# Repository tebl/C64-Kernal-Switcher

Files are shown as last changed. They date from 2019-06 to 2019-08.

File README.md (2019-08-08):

# C64 Kernal Switcher

Originally started this design with the idea of using an Arduino as a way to switch between Commodore 64 kernal ROMs, but ended up adapting BWACKs design into it instead and like him opted for the PIC12F629 instead. This particular version of a quad kernal switcher for the Commodore 64 is only compatible with Commodore 64 "longboards" (usually breadbins, but you never really know what you get with Commodore so check first).

BWACKs design has been adapted into mine, changing along the way a few of the features to my liking - in particular, reusing the original power LEDs as well as support for manual switches (find it more adaptable that way). Original pinouts and RGB headers have been kept the same in order to not have to do a manual like he did, but note that I've rotated them for easier use with angled pin headers to save on space within the newer and tighter C64C-style cases. Reusing the original LED makes it easier because RGB LEDs in a size that fits a C64C case is harder to find, not to mention fiddly to wire up for beginners with access to a soldering iron.

With only the single LED available, the code supplied with this project has been rewritten so that when you hold down the RESTORE it counts the flashes - then when you let go it performs the actions according to the following list:

1. RESET
2. Next kernal
3. Kernal 0
4. Kernal 1
5. Kernal 2
6. Kernal 3

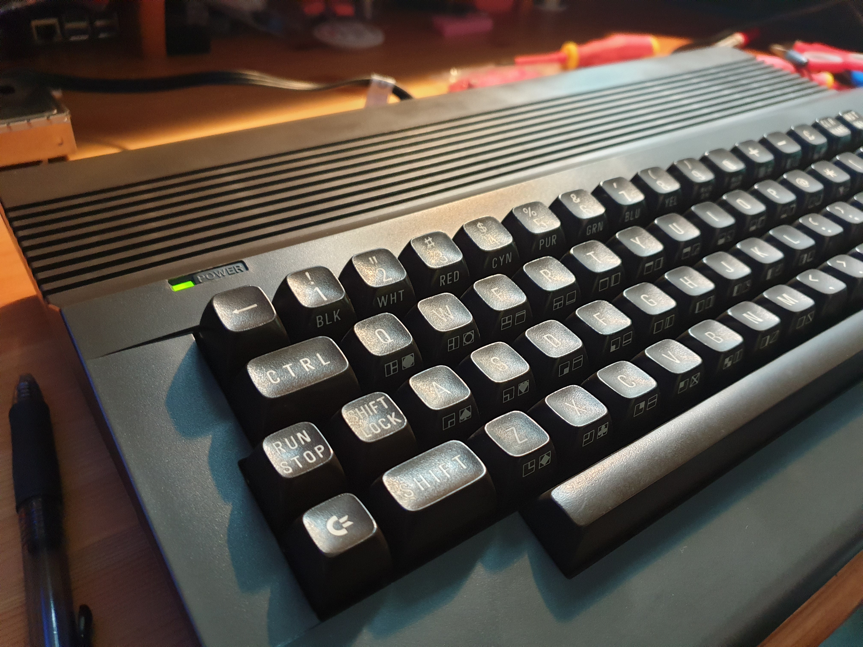
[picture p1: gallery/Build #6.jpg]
Single LED


The board itself should be functionally identical to the one made by [bwack](https://github.com/bwack/C64-Switchless-Multi-Kernal-27C256-adapter), if you want the original behavior using the RGB header with an RGB LED - use the code provided with that project.

## Building the switcher
Soldering together the few components should be easy going as long as you have access to reasonable tools, personally I'm using a cheap soldering station with adjustable temperature so no need to go expensive if you don't have to. Use 60/40 soldering tin, the lead free makes to job a lot harder if you're new to the hobby.

Start by studying the PCB, both sides and perform dry fits to see that you have an idea of where everything goes since removing things is always a lot harder than getting it right in the first place (match orientation to symbols, see gallery images for reference).

With a lot going on for such a tiny board, you'd need to pay some attention to the sequence of components getting soldered in. The list below is the one I recommend, note that with some sockets you'll have less space underneath and it'll be a lot easier getting it into place if you trim the pins after they have been soldered into place. When aligning the two 12-pin (round) pin-headers I recommend using a round-pin socket to help keep them straight, that way you won't get issues trying to install it into the Commodore 64.

1. Resistors
2. 8-pin socket (solder on reverse-side)
3. 12pin-header on the right side (solder on reverse-side)
4. 28-pin socket
5. 12-pin header on the left side (solder on reverse-side)
6. Capacitor
7. Remaining pin headers as needed

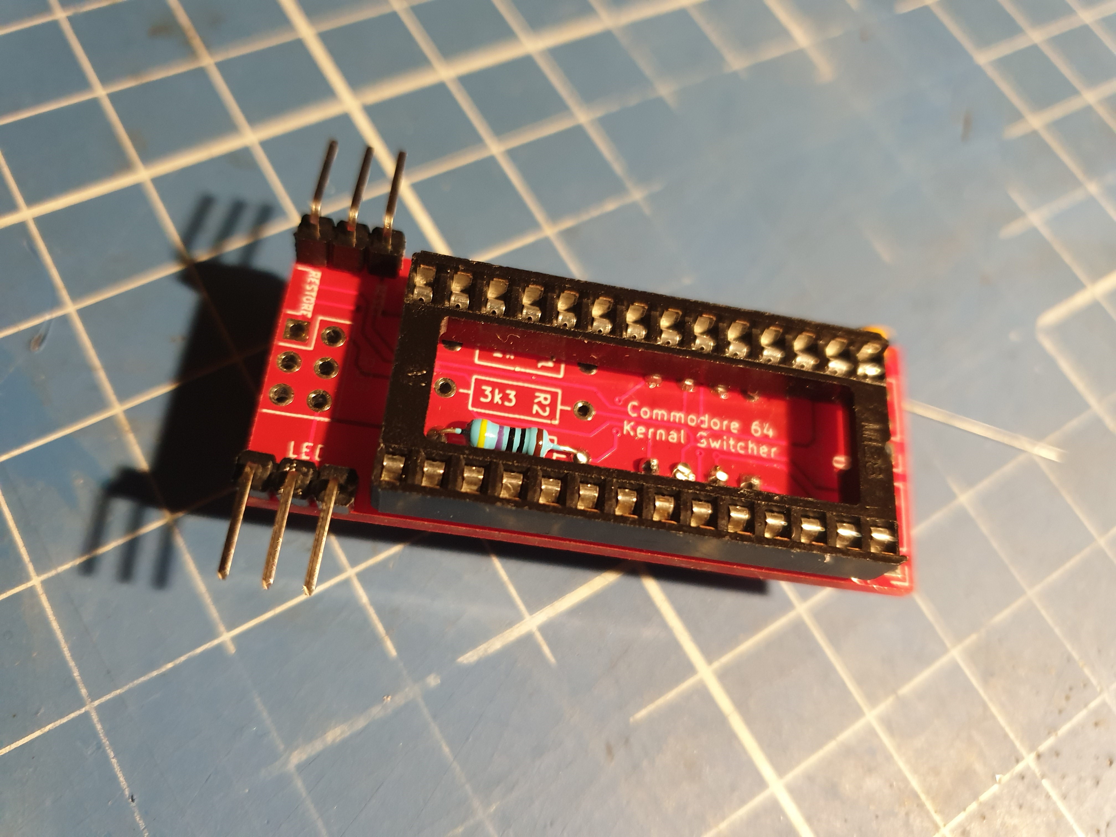
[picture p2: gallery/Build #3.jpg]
Topside

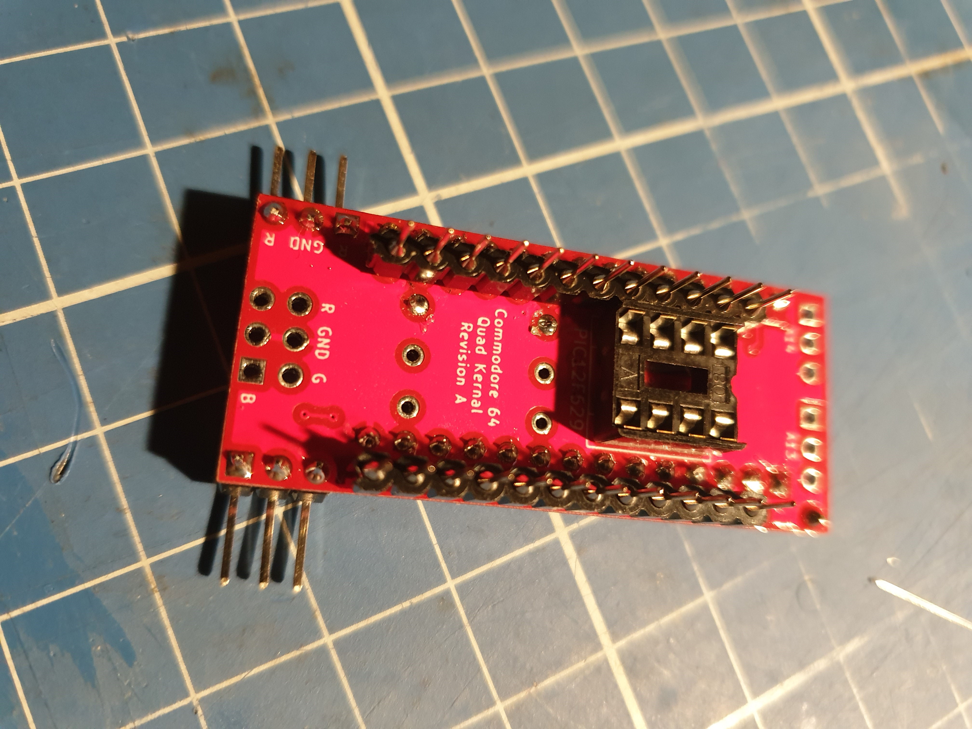
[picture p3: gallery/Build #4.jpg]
Underside


### Alternative build
The PCB doubles up as a 27c256 to 2364 adapter board, which means that you can also use it to replace the other ROM ICs used in the longboard versions of the motherboard. While there aren't many alternatives available for the basic and character ROM, but replacing them may lead to lower power use as well as decreased heat within the computer case - personally I use one as a handy way of having a 4-in-1 replacement when troubleshooting failed systems. The build process is the same as the one above, but there is no need to add resistors, 12-pin socket since the 12f629 won't be used and then add pin headers at the top in order select active ROM image. You can generate a suitable bin-file to flash 27c256 using the following command (substitute kernal4 with one of your own choice):

`copy /b basic.901226-01.bin+kernal.901227-03.bin+characters.901225-01.bin+kernal4.bin 27C256_longboard_4in1.bin`

## Installation
First of all, check that you have a C64 with a "longboard", these are physically larger - the later common C64C boards had combined basic and kernal ROMs on a single chip, requiring a different solution altogether! First locate the kernal ROM, it should be marked 901227-03 and preferably already socketed.

If it is not socketed and you don't have experience desoldering ICs from older PCBs, I would suggest that you have someone with more experience perform this task for you - if you still go through with it, you live with the consequences! If you are really doing it anyway, cut off all the legs as close to the IC as possible and then remove leftovers with tweezers and solder-braid - IC will be dead, but the board itself will probably be happier!

When installing in the computer, the pin on the bottom are inserted into the socket. You'll now need to find suitable places to attach the signal wires to the mainboard, you'll need to find a spot for the RESET and the RESTORE lines. RESET will have continuity to pin 40 on the 6510 processor, a spot for RESTORE can be found by tracing from pin 3 of the keyboard connector (pin 2 is missing). As with all things Commodore, Ray Carlsen will probably have a picture of those points for your specific revision so take a look [http://personalpages.tds.net/~rcarlsen/cbm/switchless%20JiffyDOS/](http://personalpages.tds.net/~rcarlsen/cbm/switchless%20JiffyDOS/).

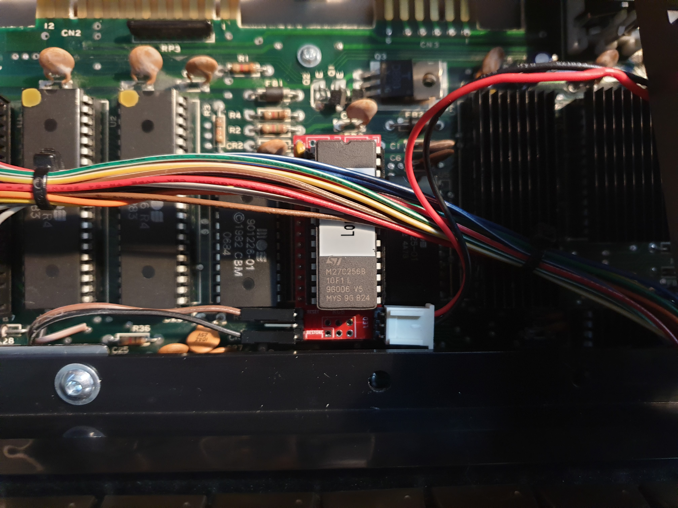
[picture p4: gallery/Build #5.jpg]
Installed


## Kernals
There have been made several kernals for the Commodore 64, this solution allows you to add 3 other kernals in addition to the original one (you'll need it for compatibility). Among my favourites are the [SD2IEC Kernal ROM](https://csdb.dk/release/?id=159050), [Turbo Tape Kernal ROM](https://csdb.dk/release/?id=47403) and [JiffyDOS](http://www.go4retro.com/products/jiffydos/). Note that JiffyDOS, while a popular choice is still under license so you should therefore seek to obtain a registered license for it!

On windows you can generate a 32kb file with your selected kernals by using the copy command, this can then be flashed to a blank 27C256 EPROM. Substitute kernals 2-4 with those of your choice:

`copy /b kernal.901227-03.bin+kernal2.bin+kernal3.bin+kernal4.bin 27C256_breadbin.bin`

Custom ROM

# Original design
As a large part of this project, schematic and code, was based on the one originally made by bwack, I've included the following section from that projects README.txt here in accordance with the license specified.

> C64 Switchless Multi Kernel Switch
> \- 27C256 rom adapter for C64's with long motherboard

> Designed by BWACK.
> CERN OPEN HARDWARE LICENSE v1.2
> http://www.ohwr.org/

> The Eagle CAD files are available on GitHub:
> https://github.com/bwack/C64-Switchless-Multi-Kernal-27C256-adapter

> All text above must be included in any redistribution

# Schematic
The supplied KiCad files should be sufficient as both a schematic and as a  starting point for ordering PCBs (basically you could just zip the contents of the export folder and upload that on a fabrication site), the schematic is also available in [PDF-format](https://github.com/tebl/C64_Kernal_Switcher/raw/master/export/C64%20Kernal%20Switcher.pdf) and this is what you'll need to print and work your way through this things don't work as expected after assembly.

# BOM
Most parts should be easy to get a hold of from your favourite local electronic component shop, but given that I don't have access to such shops where I live so everything was based on whatever I could get cheapest from ebay/AliExpress (free shipping, plan on usually waiting 3-4 weeks though). The list below should be everything you'll need in addition to a workable soldering iron and some 60/40 soldering tin. Other tools needed for this project is an EPROM-ereaser as well as an EPROM-programmer for the two ICs (I use MiniPro TL866 for both).

Pin headers you order in bulk and snap off parts as needed, but note that you should get round pin headers for the part that goes into the socket - while you can use the regular kind, you may easily wear out or break the socket.

Components in parenthesis are those used for extra features, you can omit these if you want to or have no need of those features (adding switches makes no sense if using MCU). RGB header can be left off, this is optional if you wish to use code from the original project! Sockets are always recommended though technically not needed.

| Reference | Item | Count |
| --- | --- | ----- |
| PCB | Fabricate using Gerber files ([order](https://www.pcbway.com/project/shareproject/Commodore_64_Quad_Kernal_Switcher.html?inviteid=88707)) | 1 |
| C1 | 100nF capacitor | 1 |
| R1 | 1k ohm resistor | (1) | 
| R2 | 3k3 ohm resistor | (1) |
| R3 | 560 ohm resistor | 1 |
| U1 | 12-pin straight round header | 2 |
| U2 | PIC12F629 DIP-8 | 1 |
| U2 (socket)  | 8-pin socket | (1) |
| U3 | 27C256 EPROM DIP-28 | 1 |
| U3 (socket)  | 28-pin wide socket | (1) |
| A13,A14 | 3-pin straight header | (2) |
| Signal, LED  | 3-pin angled header | 2 |
| RGB | 2x3-pin straight header | (1) |

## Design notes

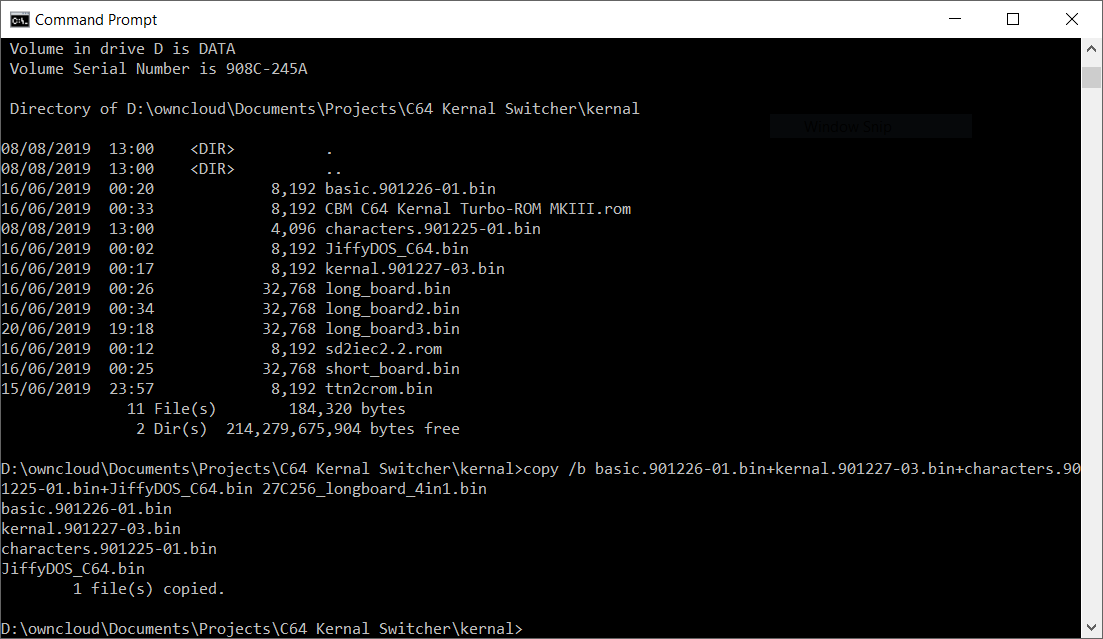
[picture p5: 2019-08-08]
gallery/27c256 #1b.PNG

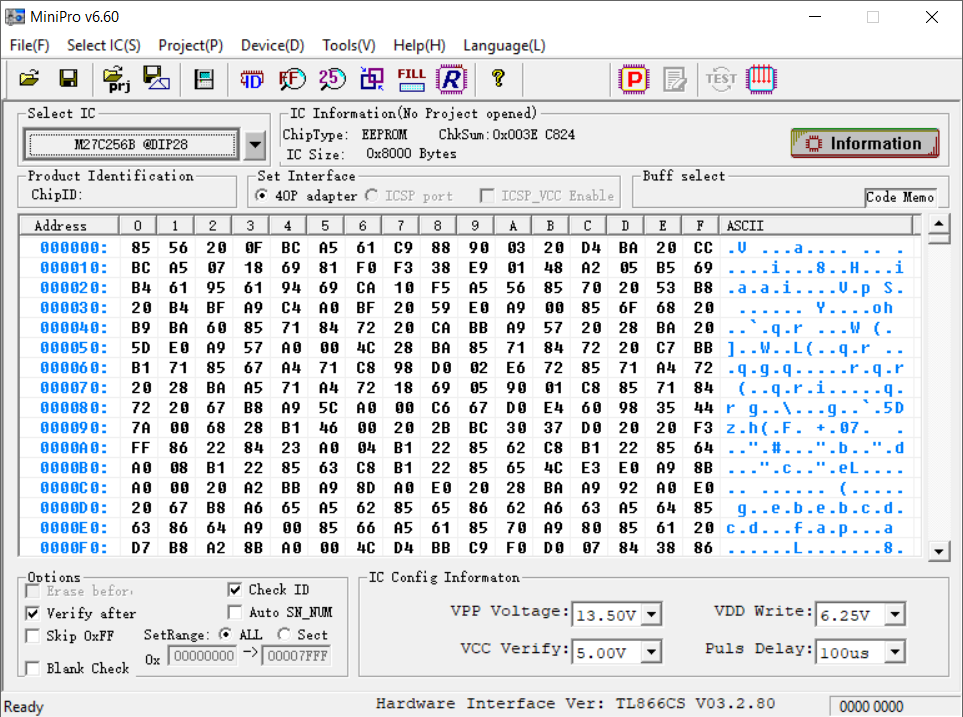
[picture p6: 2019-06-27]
gallery/27c256 #4.PNG

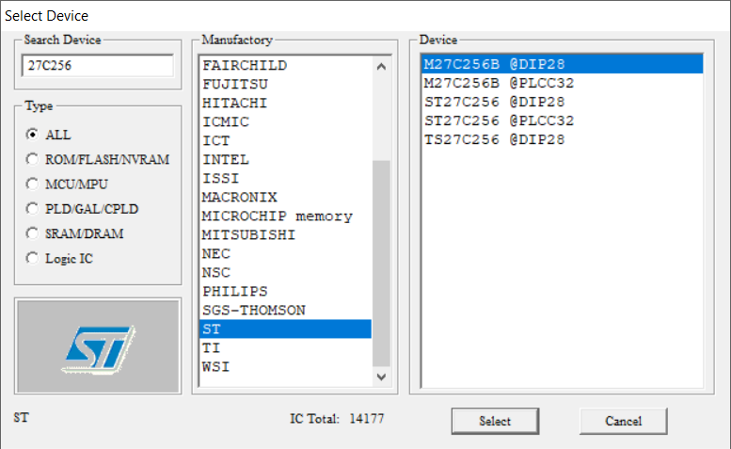
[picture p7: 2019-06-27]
gallery/27c256 #2.PNG

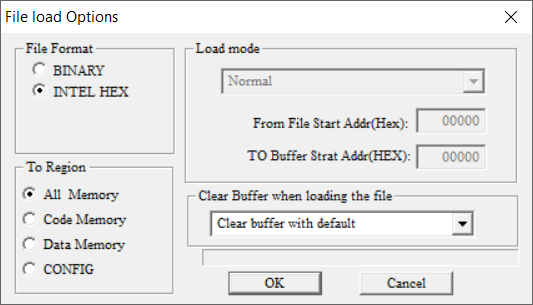
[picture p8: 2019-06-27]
gallery/12f629 #2.PNG

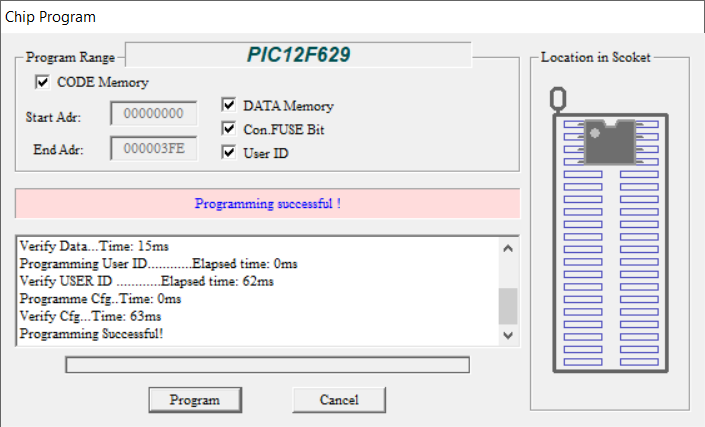
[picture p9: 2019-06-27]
gallery/12f629 #4.PNG

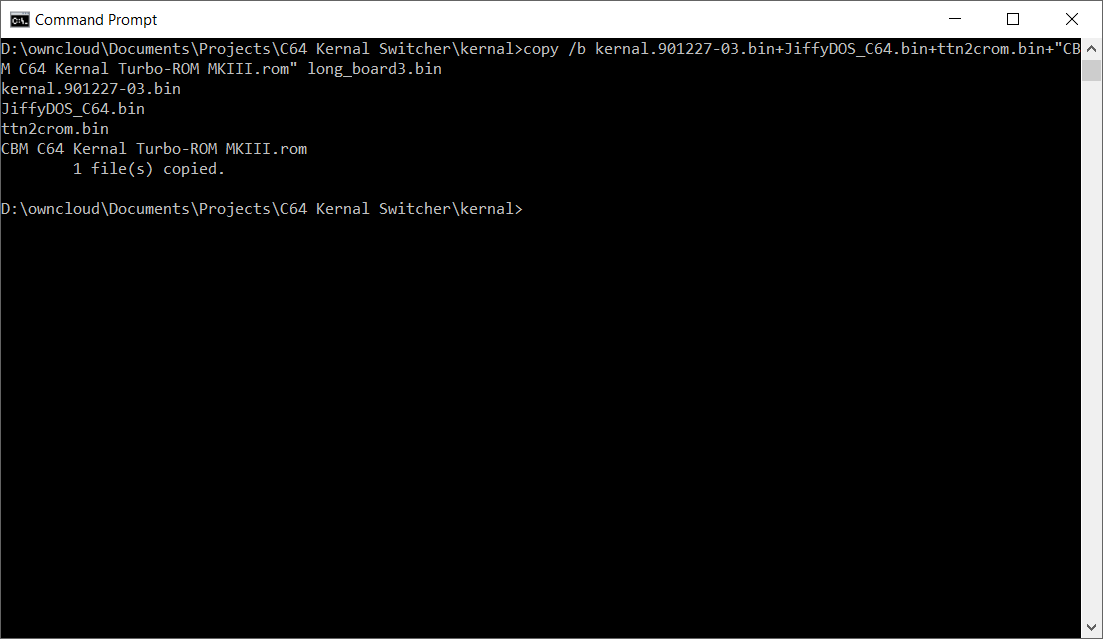
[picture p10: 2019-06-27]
gallery/27c256 #1.PNG

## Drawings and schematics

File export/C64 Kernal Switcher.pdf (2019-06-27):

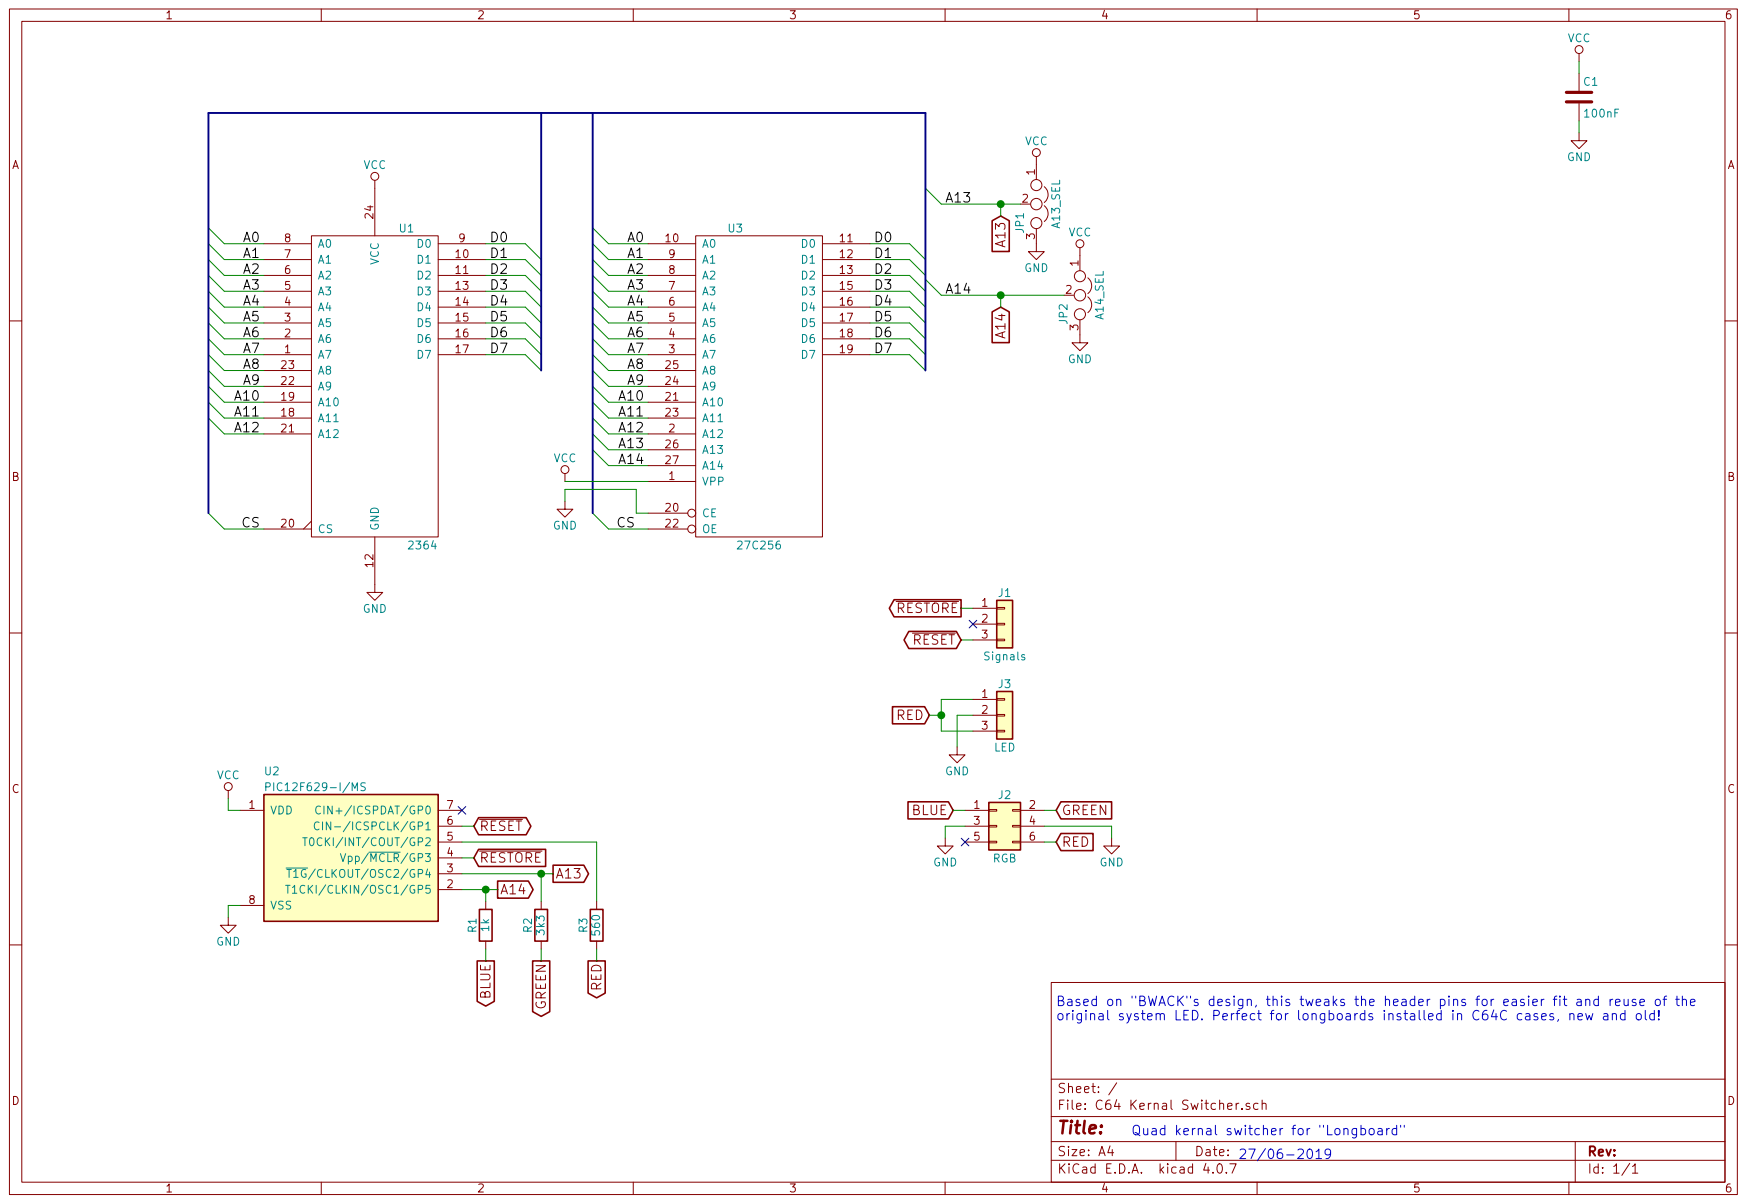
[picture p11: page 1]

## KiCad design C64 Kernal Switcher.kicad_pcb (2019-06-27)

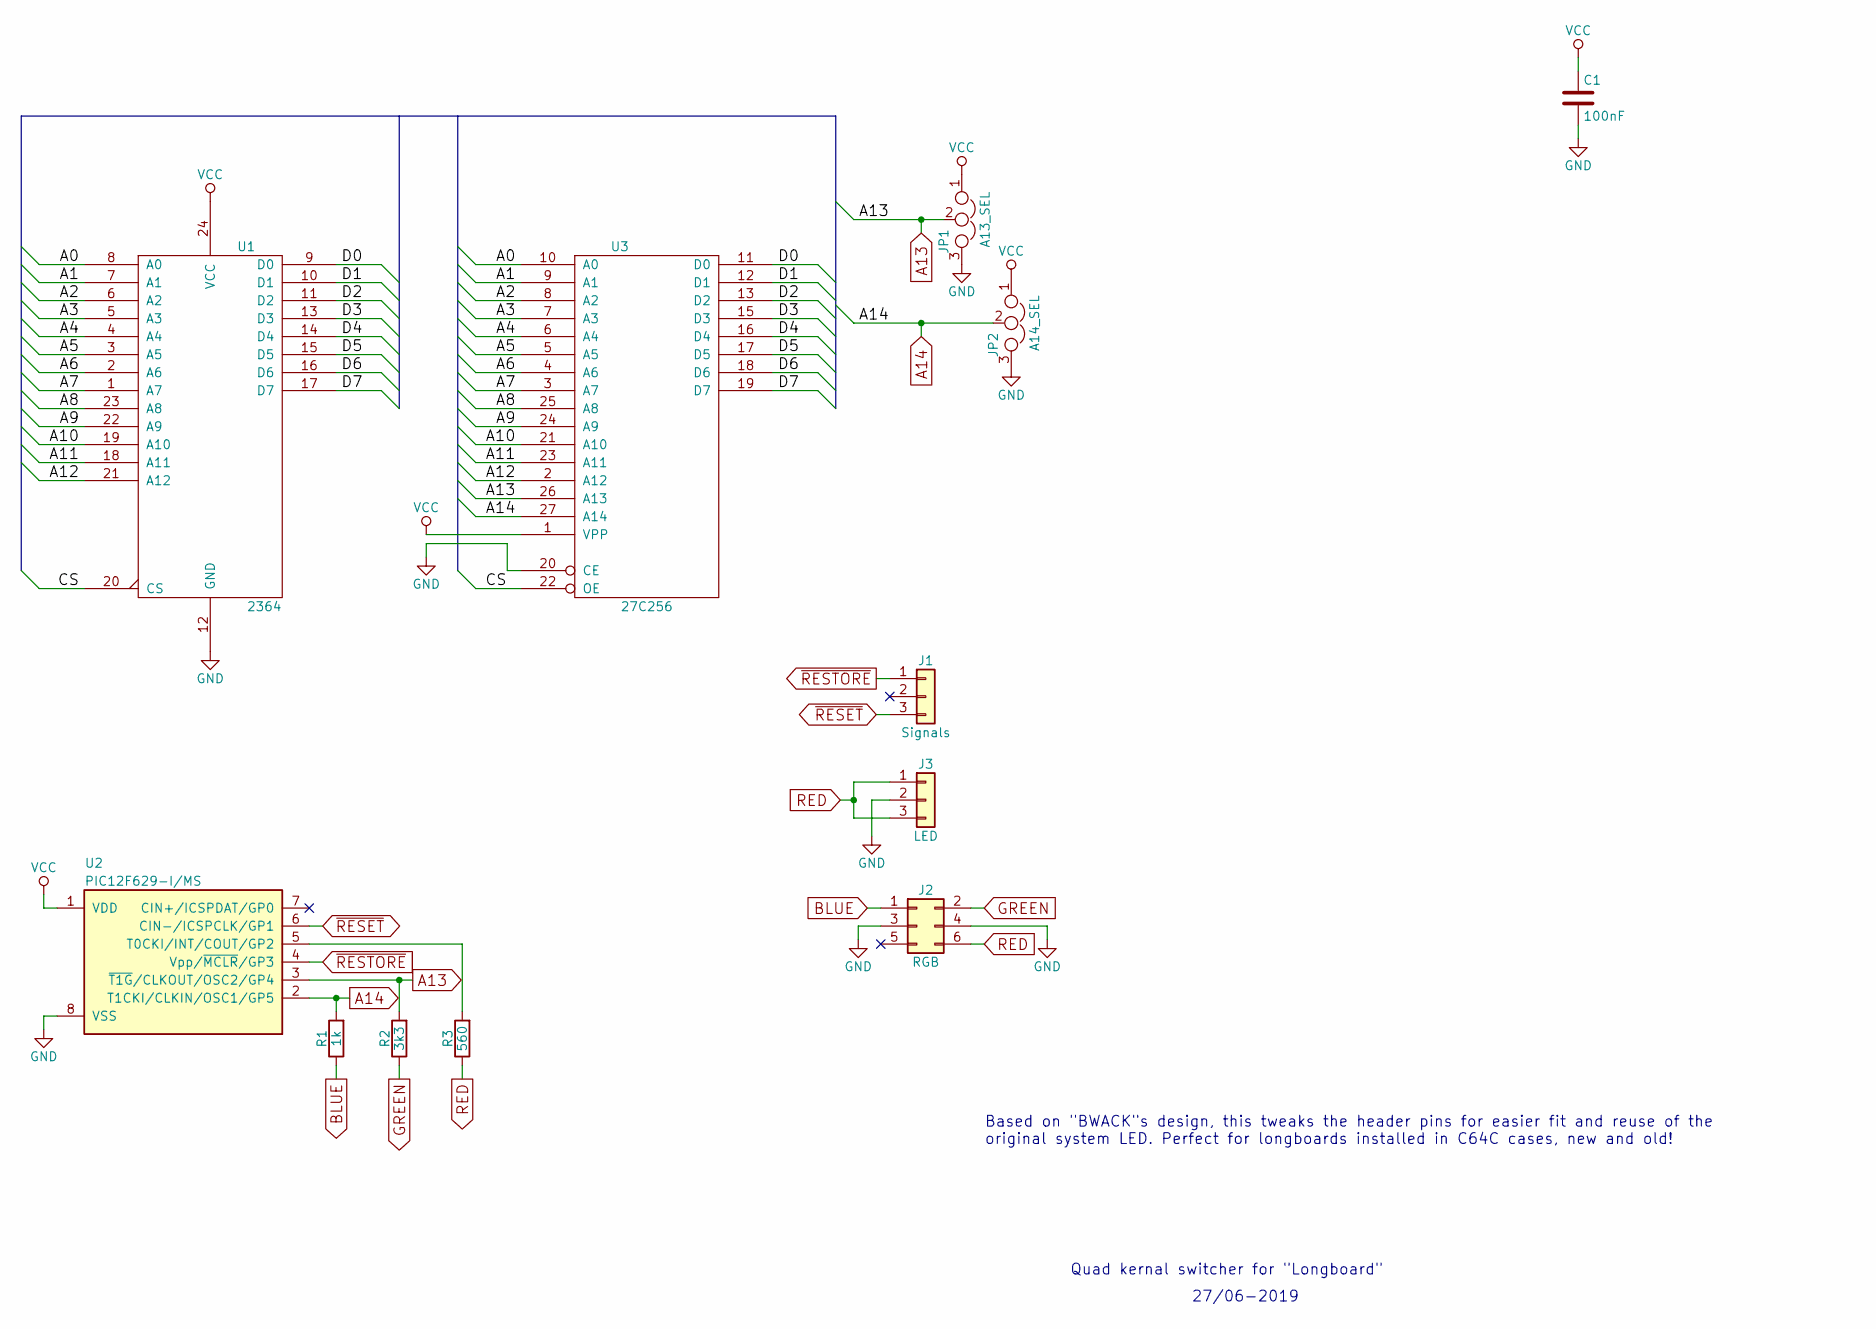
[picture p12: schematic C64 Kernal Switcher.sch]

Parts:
C1: 100nF; C_Disc_D4.7mm_W2.5mm_P5.00mm
J1: Signals; Pin_Header_Angled_1x03_Pitch2.54mm
J2: RGB; Pin_Header_Straight_2x03_Pitch2.54mm
J3: LED; Pin_Header_Angled_1x03_Pitch2.54mm
JP1: A13_SEL; Pin_Header_Straight_1x03_Pitch2.54mm
JP2: A14_SEL; Pin_Header_Straight_1x03_Pitch2.54mm
R1: 1k; R_Axial_DIN0207_L6.3mm_D2.5mm_P10.16mm_Horizontal
R2: 3k3; R_Axial_DIN0207_L6.3mm_D2.5mm_P10.16mm_Horizontal
R3: 560; R_Axial_DIN0207_L6.3mm_D2.5mm_P10.16mm_Horizontal
U1: 2364; DIP-24_W15.24mm_Socket
U2: PIC12F629-I/MS; DIP-8_W7.62mm_Socket
U3: 27C256; DIP-28_W15.24mm_Socket

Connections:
/A0: U1.8 (A0), U3.10 (A0)
/A1: U1.7 (A1), U3.9 (A1)
/A2: U1.6 (A2), U3.8 (A2)
/A3: U1.5 (A3), U3.7 (A3)
/A4: U1.4 (A4), U3.6 (A4)
/A5: U1.3 (A5), U3.5 (A5)
/A6: U1.2 (A6), U3.4 (A6)
/A7: U1.1 (A7), U3.3 (A7)
/A8: U1.23 (A8), U3.25 (A8)
/A9: U1.22 (A9), U3.24 (A9)
/A10: U1.19 (A10), U3.21 (A10)
/A11: U1.18 (A11), U3.23 (A11)
/A12: U1.21 (A12), U3.2 (A12)
/CS: U1.20 (CS), U3.22 (OE)
/D0: U1.9 (D0), U3.11 (D0)
/D1: U1.10 (D1), U3.12 (D1)
/D2: U1.11 (D2), U3.13 (D2)
/D3: U1.13 (D3), U3.15 (D3)
/D4: U1.14 (D4), U3.16 (D4)
/D5: U1.15 (D5), U3.17 (D5)
/D6: U1.16 (D6), U3.18 (D6)
/D7: U1.17 (D7), U3.19 (D7)
A13: JP1.2, R2.2, U2.3 (~T1G~/CLKOUT/OSC2/GP4), U3.26 (A13)
A14: JP2.2, R1.2, U2.2 (T1CKI/CLKIN/OSC1/GP5), U3.27 (A14)
BLUE: J2.1, R1.1
GND: C1.2, J2.3, J2.4, J3.2, JP1.3, JP2.3, U1.12 (GND), U2.8 (VSS), U3.14 (GND), U3.20 (CE)
GREEN: J2.2, R2.1
unnamed: R3.2, U2.5 (T0CKI/INT/COUT/GP2)
RED: J2.6, J3.1, J3.3, R3.1
VCC: C1.1, JP1.1, JP2.1, U1.24 (VCC), U2.1 (VDD), U3.1 (VPP), U3.28 (VCC)
~RESET: J1.3, U2.6 (CIN-/ICSPCLK/GP1)
~RESTORE: J1.1, U2.4 (Vpp/~MCLR~/GP3)

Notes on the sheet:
Quad kernal switcher for "Longboard"
Based on "BWACK"s design, this tweaks the header pins for easier fit and reuse of the original system LED. Perfect for longboards installed in C64C cases, new and old!
27/06-2019

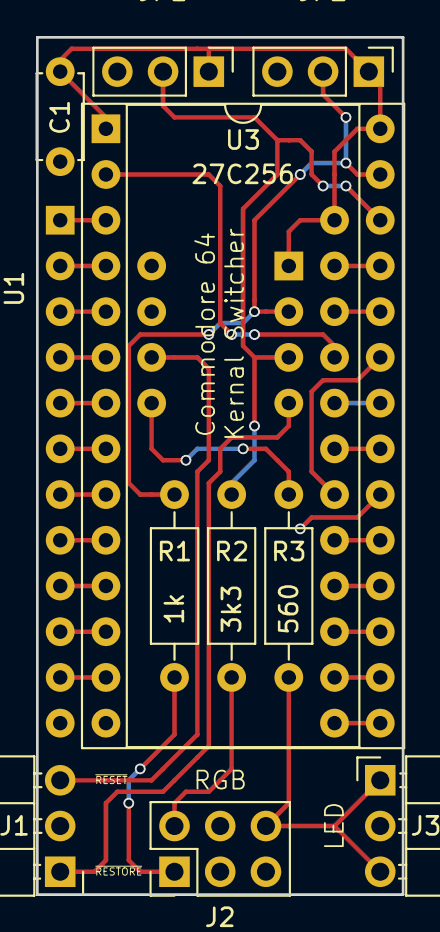
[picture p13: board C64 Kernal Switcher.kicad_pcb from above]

Board: 2 copper layers, 20.3 x 47.6 mm, 12 parts (1 on the bottom side), 32 nets.

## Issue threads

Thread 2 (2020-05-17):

General Questions

thehitponcho, 2020-05-17:
Hello @tebl

I'm a bit of a noob, so please forgive these questions if they seem simplistic.

- Are JP1 and JP2 used to manually switch between the different ROMs?
- What modifications can be made to these boards if we just want to use them as a 2332/2364 to 2732/2764 adapter?
- The original project from BWACK that this project was created from is now using an ATtiny85 chip instead of the PIC. Is it possible to do the same with your boards (with or without modifications)?

Regards

tebl, 2020-05-17:
Yes, the switches allow you to manually set rhe activated kernal, that way
you could potentially have a replacement for basic, kernal and character
ROM in one as well (without installing the PIC).

Attiny chip does not have the same pinouts so I would expect rewireing to
make fit.

søn. 17. mai 2020, 23:37 skrev Poncho <notifications@github.com>:

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

thehitponcho, 2020-05-18:
Thank you for your reply. I plan on ordering 5 boards from PCBWay soon. I will use 1 or 2 boards to make KERNEL ROMs each with multiple kernels. Then I would like to use the remaining boards for backup BASIC and CHARACTER ROMs.

Does this board support all of the 27xx EPROMS (i.e.  2764, 27256 and 27512) ?

Do you have any documentation on how the switches must be configured to use the different sized EPROMS?

tebl, 2020-05-18:
You'd have to check the datasheets for the specifics, but the board was
designed with the 27c256 in mind. 27c64 should work when leaving a13/a14
unjumpered. 27c512 should work if you flash the data two times
sequentially, but you would not get the intended capacity though I have not
tested it myself.

man. 18. mai 2020, 06:52 skrev Poncho <notifications@github.com>:

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

thehitponcho, 2020-05-19:
Thank you for all your help. BTW - I have already ordered your Joystick Switcher. I am still waiting for the parts to arrive and am quite excited to build these. Thanks for all your hard work.

Closed 2021-01-31.

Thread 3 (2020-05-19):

kernal,char and basic all in one rom

arjanv, 2020-05-19:
Hi, is it possible to use this or can you make on for me(not for free).
I really want a switchless rom switcher and also one rom to replace all three roms from a longbaord.
And maybe 2 kernals, 2 char and 1 basic rom.
Can i use this or what needs to be changed?
Thank, i hope you read this.

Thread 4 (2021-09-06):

C64 250407 board and reset line

C64Retro, 2021-09-06:
Hi
I have discovered an issue with C64 250407 board revision which has the combined internal/external reset circuitry.
When a real1541II drive is attached and powered on, powering off the C64 will start the 1541II drive motor which will keep spinning. Normally on C64 poweroff the drive should not spin. In this instance, measuring the voltage of the reset pin 6 with C64 off is around 1.4-1.6 volts with reset wire attached to kernal switcher module. Removing the wire results in the voltage going to 2.8 volts which is what the voltage is on stock C64's with revisions 250407 (combined reset circuitry) and revision 250425 (separate reset circuitry). Doing the same test with the kernal module on the 250425 board (with the separate reset circuitry), the voltage is normal at 2.8 volts.
The reset wire goes to pin 6 of the pic controller and is being pulled down to the level where the 1541II is detecting a reset.
What can be done to overcome this behaviour? Look forward to a solution.

Cheers Brad

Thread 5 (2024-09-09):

Ray Carlsen's site has moved, here is the updated link to the pictures showing RESET/RESTORE solder points

dburr, 2024-09-09:
`https://portcommodore.com/rcarlsen/cbm/switchless%20JiffyDOS/`

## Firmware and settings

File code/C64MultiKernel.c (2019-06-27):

// C64MultiKernel.c Rev 1.14 (2019-06-17)
// coded by BWACK in mikroC, rewritten by TEBL for single LED.


// Multikernel switcher for the C64 breadbin/longboard
// a 2332 ROM to 27C256 ROM adapter with four kernels
// The microcontroller program flips through the four kernels by holding down
// the RESTORE-key, in other words its a 'switchless' design. Red LED will flash
// according to action, counting the flashes with 1 being reset, 2 is next 
// kernal and the subsequent will jump to a specific kernal.

// MCU: PIC12F629 or PIC12F675
// EasyPIC5 development board
// use any pic-programmer and load the .hex file with same name as your PIC

// Project settings:
// 4MHz Intosc - I/O on GP4
// All functions disabled (MCLR, brownout etc.)


// changes:
//   2019-06-17 Rev 1.14 - Rewritten for single RGB
//   2017-11-02 Rev 1.13.1 - Added support for PIC12F675
//   2016-10-22 Rev 1.13 - putting the mcu to sleep
//   2016-09-17 Rev 1.12 - removed kernal=0. Switch-case state machine.

//#define DEBUG // uncomment this before debugging

// Inputs:
#define RESTORE_N GP3_bit
// Outputs:
#define RED_LED   GP2_bit
#define INTRST_N  GP1_bit // open-collector
// Addresses on GPIO B4 and B5

// finite state machine
#define IDLE_STATE 0
#define WAIT_RELEASE 1
#define KERNAL_TOGGLE 2
#define KERNAL_SET 3
#define RESET 4

char STATE=IDLE_STATE;
char cycle=0,buttontimer=0, old_button;
char kernalno=0;

void setkernal(char _kernal) {
  GP4_bit=0;
  GP5_bit=0;
  GPIO|=kernalno<<4;
#ifndef DEBUG
  EEPROM_Write(0x00,kernalno);
#endif
}

void toggleKernal(void) {
  kernalno++;
  kernalno&=0x03;
  setkernal(kernalno);
}

void intres(void) {
  INTRST_N=0;
  TRISIO.B1=0; // pull INTRES_N low
  RED_LED=~RED_LED;
  delay_ms(50);
  RED_LED=~RED_LED;
  delay_ms(200); // was 500
  TRISIO.B1=1; // release INTRES_N
  INTRST_N=1; // for the debugger
}

void setLED(void) {
  RED_LED = 1;
}

void blinkLED(void) {
  RED_LED=~RED_LED;
  delay_ms(100);
  RED_LED=~RED_LED;
  delay_ms(100);
}

void init(void) {
  char _i;
  OPTION_REG=0;
//  OPTION_REG=0b0001110; // about 1s watchdog timer.
  WPU.WPU1=1;
  CMCON=0x07; // digital IO
#ifdef P12F675
  ANSEL=0;
#endif
  
//ANSEL=0; // only defined for pic12f675
  TRISIO=0b00001011;
  INTRST_N=1;
  RESTORE_N=1;
  RED_LED=0;
#ifndef DEBUG
  kernalno=EEPROM_READ(0x00);
#endif
  GP3_bit=1; // presetting inputs for the debugger
  if(kernalno>3) kernalno=0; // incase EEPROM garbage.
  setkernal(kernalno);
  intres();

  IOC = 0b00001010; // GPIO interrupt-on-change mask
  GPIE_bit=1;       // GPIO Interrupt enable, on
  GIE_bit=0;        // Globale interrupt enable, off

  for(_i=0; _i<5; _i++) {
    //asm { CLRWDT };
    RED_LED=1;
    delay_ms(50);
    RED_LED=0;
    delay_ms(50);
  }
}

void main() {
  char i;
//  asm { CLRWDT };
  init();

  while(1) {
    setLED();

    switch(STATE) {
      case IDLE_STATE:
        if(!RESTORE_N || !INTRST_N) {
          buttontimer++;
          delay_ms(100);
        } else {
          if (cycle > 0) {
            STATE=WAIT_RELEASE; old_button=0; buttontimer=0;
          } else {
            buttontimer=0;
            asm {sleep};
            GPIF_bit=0;

            delay_ms(100);
          }
        }

        // Bump cycle counter
        if (buttontimer > 10) {
          cycle++; buttontimer=0;
          blinkLED();
        }
        break;

      case WAIT_RELEASE:
        switch (cycle) {
          case 1:
            STATE=RESET;
            break;
          case 2:
            STATE=KERNAL_TOGGLE;
            break;
          case 3:
            STATE=KERNAL_SET;
            kernalno=0;
            break;
          case 4:
            STATE=KERNAL_SET;
            kernalno=1;
            break;
          case 5:
            STATE=KERNAL_SET;
            kernalno=2;
            break;
          case 6:
            STATE=KERNAL_SET;
            kernalno=3;
            break;
          default:
            STATE=RESET;
            break;
        }
        
        cycle=0;
        break;

      case KERNAL_TOGGLE:
        STATE=RESET;
        toggleKernal();
        delay_ms(20);
        break;
        
      case KERNAL_SET:
        STATE=RESET;
        setkernal(kernalno);
        delay_ms(20);
        break;

      case RESET:
        STATE=IDLE_STATE;
        intres();
        buttontimer=0;
        break;

      default:
        break;
    }
  }
}

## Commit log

2019-04-29 Basic schematic
    [C64 Kernal Switcher.kicad_pcb, C64 Kernal Switcher.sch]
2019-04-29 Fixed footprints
    [C64 Kernal Switcher.kicad_pcb, C64 Kernal Switcher.sch]
2019-04-29 PCB layed out, need measuring
    [C64 Kernal Switcher.kicad_pcb, C64 Kernal Switcher.sch]
2019-06-17 Changed to PIC like bwack's design
    [C64 Kernal Switcher.sch]
2019-06-17 Assigned footprints
    [C64 Kernal Switcher.sch]
2019-06-17 Layout redone
    [C64 Kernal Switcher.kicad_pcb, C64 Kernal Switcher.sch]
2019-06-17 Added updated code
    [C64MultiKernel.cfg]
2019-06-17 Updated silkscreen
    [C64 Kernal Switcher.kicad_pcb, C64 Kernal Switcher.sch]
2019-06-17 Gerber export
    [C64 Kernal Switcher-B.Cu.gbl, C64 Kernal Switcher-B.Mask.gbs, C64 Kernal Switcher-B.Paste.gbp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]
2019-06-27 Moved R1 so it fits better under socket
    [C64 Kernal Switcher-B.Cu.gbl, C64 Kernal Switcher-B.Mask.gbs, C64 Kernal Switcher-B.Paste.gbp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]
